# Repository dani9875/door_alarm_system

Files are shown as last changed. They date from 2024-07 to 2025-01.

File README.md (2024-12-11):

# Door alarm system
This project is a DIY smart door alarm system designed to enhance property security by providing real-time monitoring and notifications. The system detects whether a door has been opened or closed and instantly reacts to these events.

When a change is detected, the system transmits the event data through the local network to cloud services. The cloud then relays the information to a mobile application, alerting the property owner via a notification. This ensures the owner is promptly informed whenever someone enters or leaves the property.

*In case you are interested in making your own instance, please find the HW manufacturing files under the release tab.*

# How to build, flash and monitor the output the firmware
0. Check out the repository

1. Navigate to the `door_alarm_fw` directory:  
   ```bash
   cd door_alarm_fw
   ```

2. (Once) Build the Docker image by executing the following script if you have not done yet:  
   ```bash
   ./docker_build.sh
   ```

3. After the Docker image is successfully built, start the container using:  
   ```bash
   ./docker_start.sh
   ```

4. Configure the followings in *main.c* manually before build:

   ```c
   #define EXAMPLE_ESP_WIFI_SSID      "AP"
   #define EXAMPLE_ESP_WIFI_PASS      "password"

   #define EXAMPLE_STATIC_IP_ADDR        "192.168.0.100"
   #define EXAMPLE_STATIC_GW_ADDR        "192.168.0.1"
   #define EXAMPLE_STATIC_NETMASK_ADDR   "255.255.255.0"

   #define HOST "us-east-1-1.aws.cloud2.influxdata.com"
   #define PATH "/api/v2/write?orgID=[org_id]&bucket=[bucket_name]&precision=ns"
   #define TOKEN "Token [INFLUX_DB TOKEN]"
   ```

5. Inside the container, build the firmware by running:  
   ```bash
   ./build_firmware.sh
   ```

6. To program the firmware onto the device, use:  
   ```bash
   ./burn_firmware.sh
   ```

7. If you wish to observe the firmware's output, execute the monitoring script:  
   ```bash
   ./monitor_firmware.sh
   ```

## Release notes

### Version: v3.0
Changelog:
- Voltage divider resistor change
- Component library update

### Version: v2.0
Changelog:
- Component library organised
- Fuse introduced
- IP4283CZ10-TBR,115 ESD diodes

### Version: v1.0
Changelog:
- USB capability (does not work)
- USB active LED (erroneously glows even when operating from battery)
- Debug programming header
- Reed switch gate 
- Debug LED
- Voltage sense

# Technical solutions
The heart of the device is the reed sensor, which operates in normally open mode (the circuit remains open when the magnet and the reed sensor are aligned). This design choice minimizes power consumption, as no current is drawn when the door is closed. The system remains in deep sleep mode most of the time and can only be interrupted by an interaction, such as opening or closing the door. When the system wakes up, it checks the battery charge level and the door status, then initializes the WiFi connection to transmit this data to the cloud. 

A time-series data platform, [Influx](https://cloud2.influxdata.com/signup), is used to collect the data, and the data is forwarded to [Grafana](https://grafana.com/) for visualization. You can find the `grafana_door_alarm_system.json` file in the docs, which you can import to create a dashboard for monitoring the door status and battery level. Make sure to set the source ID (UID) to ensure proper functionality. 

If you would like to receive notifications about state changes, I recommend visiting [IFTTT](https://ifttt.com/explore). You can trigger events and subscribe to them. The ideal solution is to create a webhook that can be triggered from the ESP32 when it wakes up. However, this is a PRO feature. If you want to stay within the free tier, you can create a Google Sheet, set it as a trigger, and add a row (GDrive API is enabled). When a row is added, the subscriber can receive a WhatsApp message (note that with the free plan, the message may be delayed up to 1 hour).

### V2
After the component placement, I realized that the voltage measurement enable pin pad came off, so I rewired it to the LED enable pin. As a result, every time I measure the battery level, the LED briefly lights up. I also didn't have a fuse in my inventory, so I bypassed it with a direct connection. Since USB communication was functioning properly, I decided not to add the H1 straight header pins.

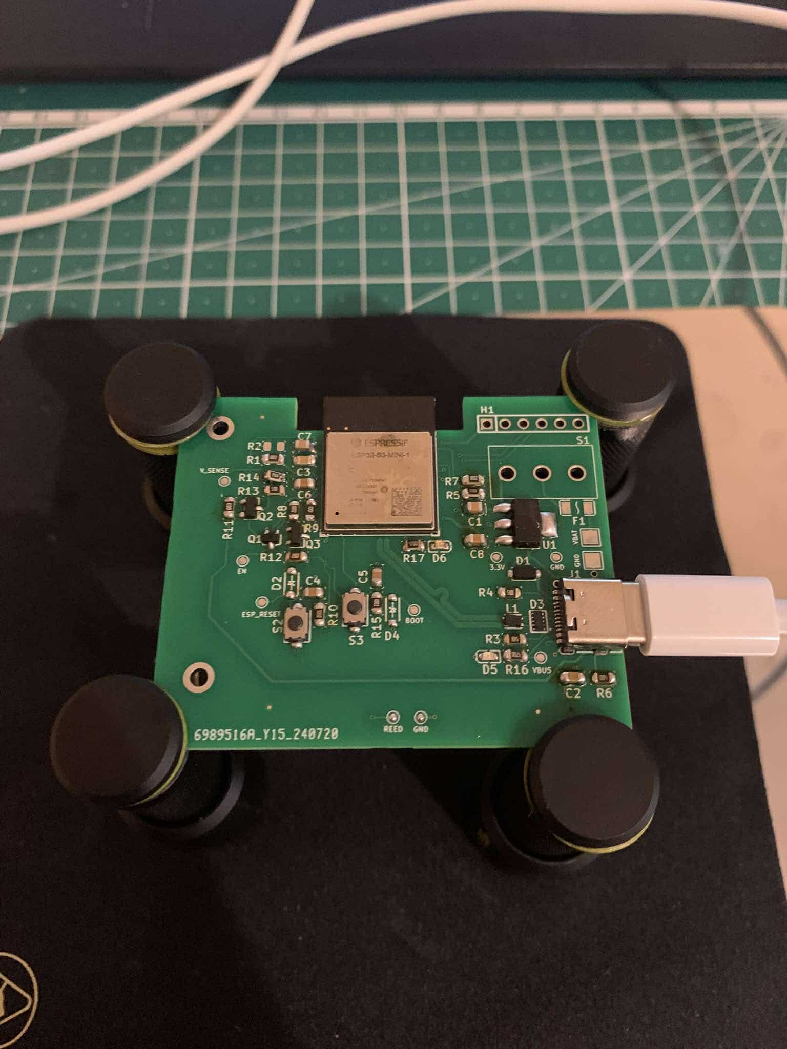
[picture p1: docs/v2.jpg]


**How to check if the USB interface is working properly:**

Run ```lsusb``` and look for a device called ```Espressif USB JTAG/serial debug unit``` 

```bash
root@c7cc3ff0b21c:/project# lsusb
Bus 004 Device 001: ID 1d6b:0003  
Bus 003 Device 003: ID 046d:c52b Logitech USB Receiver
Bus 003 Device 002: ID 13d3:54b1 Azurewave Integrated Camera
Bus 003 Device 021: ID 303a:1001 Espressif USB JTAG/serial debug unit
Bus 003 Device 004: ID 0bda:c123 Realtek Bluetooth Radio
Bus 003 Device 001: ID 1d6b:0002  
Bus 002 Device 001: ID 1d6b:0003  
Bus 001 Device 001: ID 1d6b:0002 
```

**A short code snippet (main.c, app_main()) that allows you to check if the general LED blinks:**
```c
const uint8_t led_en = GPIO_NUM_14;

void app_main(void)
{
    gpio_reset_pin(led_en);
    gpio_set_direction(led_en, GPIO_MODE_OUTPUT);

    while(1)
    {
        gpio_set_level(led_en, 1);
        vTaskDelay(pdMS_TO_TICKS(1000));
        gpio_set_level(led_en, 0);
        vTaskDelay(pdMS_TO_TICKS(1000));
    }   

    return;
}
```
In a short test, I approached the reed sensor with the magnet, which triggered a wake-up event (the LED lights up). While I held the magnet in place, nothing further happened, and the device went back to sleep. As soon as I removed the magnet, the LED flashed again, indicating that the system had woken up, similar to how it would behave if the door were opened. </br>


Although I did not have a proper casing the setup was mounted above the entrance to collect data and analyze power consumption. Data was being monitored in Grafana. 


</br>

### V1
The first version was revised because the USB interface did not work at all, and it wasn’t even impedance-controlled. As a result, it had to be programmed via the UART interface using a USB-to-TTL adapter.
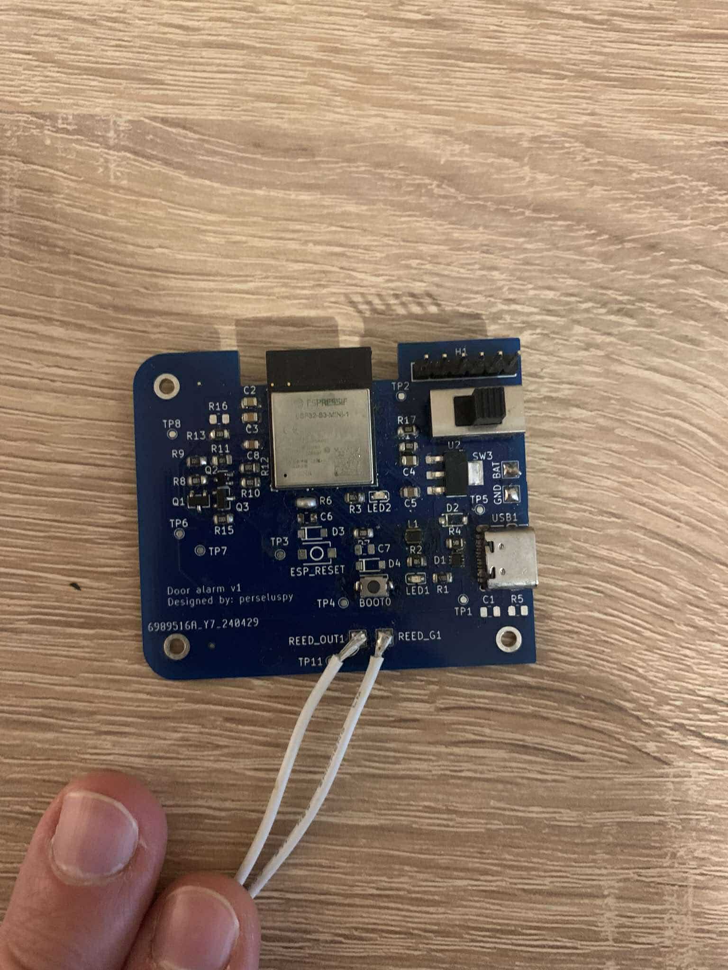
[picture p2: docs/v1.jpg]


## Consumption calculations
Power usage estimates assume the application wakes up 6 times a day (3 times for door opening and 3 times for door closing), and the system is powered by 4 AA batteries with average capacity.

| **Component** | **Current (µA)** | **Time (s)** | **Energy Contribution (µA·s)** | **Comment** |
|---|---|---|---|---|
| AP2114HA-3.3TRG1 | 60 | 86400 | 60*86400 = 5184000  | LDO operates at all times. |
| ESP32 awake doing its job  | 300000 | 60 | 300000*60 = 18000000| Wake-up duration is approximately 10 seconds. |
| Battery measurement | 240 | 60 | 240*60 = 14400 | V_SENSE divider: ~ (6 V / 25000 Ω) = 240 µA, active only during wake-up periods. |
| Reed switch closed (door open) | 330 | 45 | 330*45 = 14850 | The door is left open for a maximum of 15 seconds, and this state occurs during half of all activities. |
| ESP32 deep sleep mode | 8 | 86340 | 8*86340 = 690720 | ESP32 consumes minimal power during deep sleep. |

#### Total Energy Contribution (µA·s):
$$
5184000 + 18000000 + 14400 + 14850 + 690720 = 23903970 \ \text{µAs}
$$

#### Average Current per day (µA):
$$
\text{Average Current} = \frac{23903970}{86400} \approx 276 \ \text{µA}
$$

**Assumptions:**
**4 AA batteries** in series: Each AA battery provides **1.5V**, and the combined voltage will be **6V**. **Capacity of AA batteries**: We'll assume **2000 mAh** for typical alkaline AA batteries. **Average current consumption**: **276 µA** (0.276 mA).
</br>

#### Battery life in hours can be calculated by dividing the total battery capacity by the current draw:

$$
\text{Battery Life (hours)} = \frac{\text{Battery Capacity (mAh)}}{\text{Current Consumption (mA)}}
$$

#### For **2000 mAh** batteries and **0.276 mA** current:

$$
\text{Battery Life (hours)} = \frac{2000}{0.276} \approx 7246 \, \text{hours}
$$

#### Convert this to days:

$$
\text{Battery Life (days)} = \frac{7246}{24} \approx 302 \, \text{days}
$$

**Calculation here is not final since batteries are not drained to 0 V. Will be added after some testing. LDO shall be fed at least from 4V.** 

## Limitations/what could be improved
- HW routing is not ideal
- Local wifi credentials and static IP as well as INFLUX_DB credentials must be compiled into the project and must be set from source code
- Consumptions increase when the door is open (around 400-500 uA)
- HW and FW project is tightly-coupled making versioning obscure
- Voltage divider resistors are mixed up
- Creation of a elegant enclosure is lacked
- Some FW clean-up

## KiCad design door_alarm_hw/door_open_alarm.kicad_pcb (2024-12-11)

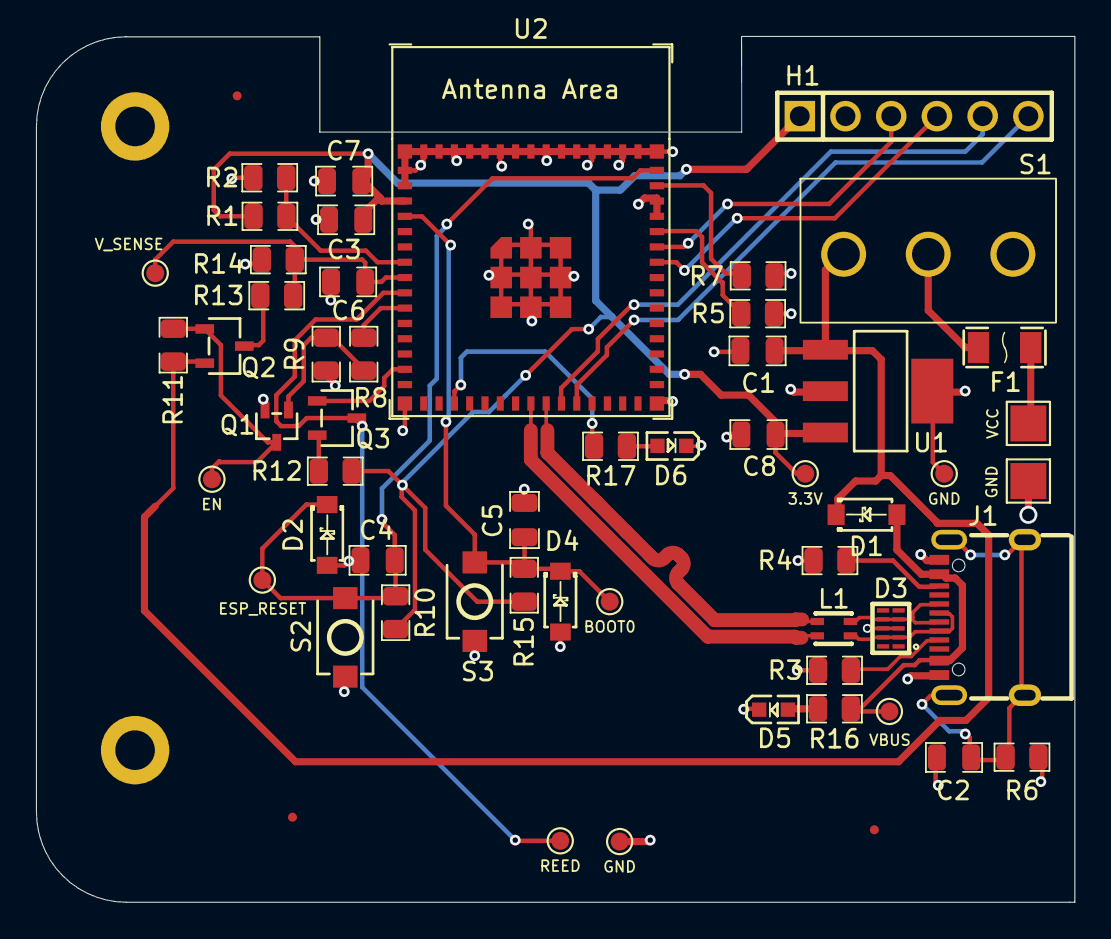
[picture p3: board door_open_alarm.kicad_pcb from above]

Board: 2 copper layers, 57.7 x 48.1 mm, 59 parts (0 on the bottom side), 33 nets.

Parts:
C1, C3, C7: CL21A106KOQNNNE; [CAP_SMD_0805_2012Metric]
C2, C8: CC0805KRX7R9BB104; [CAP_SMD_0805_2012Metric]
C4, C5, C6: C0805C105M4VACTU; [CAP_SMD_0805_2012Metric]
D1, D2, D4: STPS140Z; [SCHOTTKY_DIODE_40V]STMicroelectronics STPS140Z
D3: IP4283CZ10-TBR,115; [ESD_PROT]Nexperia IP4283CZ10-TBR,115
D5, D6: LTST-C190KRKT; [LED]Lite-On LTST-C190KRKT
F1: 0466.200NRHF; [FUSE_SMD_1206]
FID1, FID2, FID3: Fiducial; Fiducial_0.5mm_Mask1mm
H1: PZ254V-11-06P; [6P_HEADER_STR]XFCN PZ254V-11-06P
J1: TYPE-C 16PIN 2MD(073); [USB_C_16P_RA_FEMALE]SHOU HAN TYPE-C 16PIN 2MD(073)
L1: DLW21SN900SQ2L; [COMMON_MODE_FILTER]Murata Electronics DLW21SN900SQ2L
MH1, MH2: [MOUNTING_HOLE]MountingHole_2.2mm_M2_DIN965_Pad
Q1: BSS138PW,115; [NMOS]Nexperia BSS138PW,115
Q2, Q3: CJ2301 S1; [PMOS]Jiangsu Changjing Electronics Technology Co., Ltd. CJ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
R1, R2, R5, R7, R9, R10, R12, R15: 0805W8F1002T5E; [RES_SMD_0805_2012Metric]
R3, R4, R14: 0805W8F5101T5E; [RES_SMD_0805_2012Metric]
R6: 0805W8F1004T5E; [RES_SMD_0805_2012Metric]
R8: 0805W8F1001T5E; [RES_SMD_0805_2012Metric]
R11: 0805W8F1003T5E; [RES_SMD_0805_2012Metric]
R13: 0805W8J0203T5E; [RES_SMD_0805_2012Metric]
R16, R17: 0805W8F4700T5E; [RES_SMD_0805_2012Metric]
S1: SS-12D10L5; [SLIDE_SWITCH]XKB Connection SS-12D10L5
S2, S3: TS-1088-AR02016; [TACTILE_SWITCH]XUNPU TS-1088-AR02016
TP1: VBUS; [TEST_POINT]TestPoint_Pad_D1.0mm
TP2: VCC; [TEST_POINT]TestPoint_Pad_2.0x2.0mm
TP3: GND; [TEST_POINT]TestPoint_Pad_2.0x2.0mm
TP4, TP6: GND; [TEST_POINT]TestPoint_Pad_D1.0mm
TP5: 3.3V; [TEST_POINT]TestPoint_Pad_D1.0mm
TP7: ESP_RESET; [TEST_POINT]TestPoint_Pad_D1.0mm
TP8: EN; [TEST_POINT]TestPoint_Pad_D1.0mm
TP9: REED; [TEST_POINT]TestPoint_Pad_D1.0mm
TP10: V_SENSE; [TEST_POINT]TestPoint_Pad_D1.0mm
TP11: BOOT0; [TEST_POINT]TestPoint_Pad_D1.0mm
U1: AP2114HA-3.3TRG1; [LDO]Diodes Incorporated AP2114HA-3.3TRG1
U2: ESP32-S3-MINI-1; [MCU]Espressif Systems ESP32-S3-MINI-1-N8

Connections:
+3.3V: C3.1, C7.1, C8.2, H1.1, R1.2, R10.2, R12.2, R15.2, TP5.1, U1.3 (OUT), U2.3 (3V3)
/BOOT0: C5.2, D4.1 (C), R15.1, S3.2, TP11.1, U2.4 (GPIO0/BOOT)
/D+: D3.4 (TMDS_CH2-), D3.7 (NC), J1.6 (DP1), J1.8 (DP2), L1.4
/D-: D3.2 (TMDS_CH1+), D3.9 (NC), J1.5 (DN2), J1.7 (DN1), L1.1
/EN: Q1.3 (D), Q2.1 (G), R11.1, TP8.1
/ESP_RESET: C4.2, D2.1 (C), R10.1, S2.2, TP7.1, U2.45 (EN)
/GEN_1: H1.5, U2.25 (GPIO21)
/GEN_2: H1.6, U2.26 (GPIO26)
/LED_EN: R17.2, U2.18 (GPIO14/TOUCH14/ADC2_CH3/FSPIWP/FSPIDQS/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)
/MEAS_EN: R8.1, U2.10 (GPIO6/TOUCH6/ADC1_CH5)
/REED: Q3.3 (D), TP9.1, U2.9 (GPIO5/TOUCH5/ADC1_CH4)
/REED_EN: Q3.1 (G), U2.14 (GPIO10/TOUCH10/ADC1_CH9/FSPICS0/FSPIIO4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)
/SHIELD: C2.1, J1.13 (SHELL), J1.14 (SHELL), R6.1
/STRAP_3: R1.1, R2.2, U2.7 (GPIO3/TOUCH3/ADC1_CH2)
/STRAP_45: R5.2, U2.41 (GPIO45)
/STRAP_46: R7.2, U2.44 (GPIO46)
/U0_RX: H1.3, U2.40 (U0RXD/GPIO44/CLK_OUT2)
/U0_TX: H1.4, U2.39 (U0TXD/GPIO43/CLK_OUT1)
/USB_D+: L1.3, U2.24 (GPIO20/U1CTS/ADC2_CH9/CLK_OUT1/USB_D+)
/USB_D-: L1.2, U2.23 (GPIO19/U1RTS/ADC2_CH8/CLK_OUT2/USB_D-)
/VBUS: D1.2 (A), J1.2 (VBUS), J1.11 (VBUS), R16.2, TP1.1
/V_INPUT: C1.1, D1.1 (C), Q2.2 (S), R11.2, S1.1, U1.1 (IN)
/V_SENSE: C6.2, R13.1, R14.2, TP10.1, U2.8 (GPIO4/TOUCH4/ADC1_CH3)
GND: C1.2, C2.2, C3.2, C4.1, C5.1, C6.1, C7.2, C8.1, D2.2 (A), D3.3 (GND), D3.8 (GND), D4.2 (A), D5.2 (C), D6.2 (C), H1.2, J1.1 (GND), J1.12 (GND), MH1.1, MH2.1, Q1.2 (S), R2.1, R3.1, R4.1, R5.1, R6.2, R7.1, R9.1, R14.1, S2.1, S3.1, TP3.1, TP4.1, TP6.1, U1.2 (GND), U1.4 (GND), U2.1 (GND), U2.2 (GND), U2.42 (GND), U2.43 (GND), U2.46 (GND), U2.47 (GND), U2.48 (GND), U2.49 (GND), U2.50 (GND), U2.51 (GND), U2.52 (GND), U2.53 (GND), U2.54 (GND), U2.55 (GND), U2.56 (GND), U2.57 (GND), U2.58 (GND), U2.59 (GND), U2.60 (GND), U2.61 (GND), U2.62 (GND), U2.63 (GND), U2.64 (GND), U2.65 (GND)
unnamed: D5.1 (A), R16.1
unnamed: D6.1 (A), R17.1
unnamed: F1.2, S1.2
unnamed: J1.4 (CC1), R3.2
unnamed: J1.10 (CC2), R4.2
unnamed: Q1.1 (G), R8.2, R9.2
unnamed: Q2.3 (D), R13.2
unnamed: Q3.2 (S), R12.1
VCC: F1.1, TP2.1

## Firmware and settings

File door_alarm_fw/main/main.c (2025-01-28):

#include "cJSON.h"
#include "driver/gpio.h"
#include "driver/touch_pad.h"
#include "driver/usb_serial_jtag.h"
#include "freertos/FreeRTOS.h"
#include "freertos/event_groups.h"
#include "freertos/semphr.h"
#include "freertos/task.h"
#include <stdint.h>
#include <stdio.h>
#include "esp_log.h"
#include "minunit.h"
#include <stdlib.h>
#include "esp_adc/adc_cali.h"
#include "esp_adc/adc_cali_scheme.h"
#include "esp_adc/adc_oneshot.h"
#include <string.h>
#include "esp_sleep.h"
#include "esp_system.h"
#include "esp_wifi.h"
#include "driver/rtc_io.h"
#include "esp_event.h"
#include "nvs_flash.h"
#include "esp_http_client.h"
#include "esp_tls.h"
#if CONFIG_MBEDTLS_CERTIFICATE_BUNDLE
#include "esp_crt_bundle.h"
#endif
#include "mbedtls/ctr_drbg.h"
#include <mbedtls/entropy.h>

#include "lwip/err.h"
#include "lwip/sys.h"

/* The examples use WiFi configuration that you can set via project configuration menu

   If you'd rather not, just change the below entries to strings with
   the config you want - ie #define EXAMPLE_WIFI_SSID "mywifissid"
*/
#define EXAMPLE_ESP_WIFI_SSID      "[AP_NAME]"
#define EXAMPLE_ESP_WIFI_PASS      "[PASSWORD]"
#define EXAMPLE_ESP_MAXIMUM_RETRY  3
#define CONFIG_ESP_WIFI_AUTH_WPA2_PSK 1

#define EXAMPLE_STATIC_IP_ADDR        "[STATIC_IP]"
#define EXAMPLE_STATIC_GW_ADDR        "[GATEWAY]"
#define EXAMPLE_STATIC_NETMASK_ADDR   "[NETMASK]"

#define HOST "us-east-1-1.aws.cloud2.influxdata.com"
#define PATH "/api/v2/write?orgID=[ID]a08ec8&bucket=[BUCKET_NAME]&precision=ns"
#define TOKEN "Token [your token]"


#if CONFIG_ESP_WPA3_SAE_PWE_HUNT_AND_PECK
#define ESP_WIFI_SAE_MODE WPA3_SAE_PWE_HUNT_AND_PECK
#define EXAMPLE_H2E_IDENTIFIER ""
#elif CONFIG_ESP_WPA3_SAE_PWE_HASH_TO_ELEMENT
#define ESP_WIFI_SAE_MODE WPA3_SAE_PWE_HASH_TO_ELEMENT
#define EXAMPLE_H2E_IDENTIFIER CONFIG_ESP_WIFI_PW_ID
#elif CONFIG_ESP_WPA3_SAE_PWE_BOTH
#define ESP_WIFI_SAE_MODE WPA3_SAE_PWE_BOTH
#define EXAMPLE_H2E_IDENTIFIER CONFIG_ESP_WIFI_PW_ID
#endif
#if CONFIG_ESP_WIFI_AUTH_OPEN
#define ESP_WIFI_SCAN_AUTH_MODE_THRESHOLD WIFI_AUTH_OPEN
#elif CONFIG_ESP_WIFI_AUTH_WEP
#define ESP_WIFI_SCAN_AUTH_MODE_THRESHOLD WIFI_AUTH_WEP
#elif CONFIG_ESP_WIFI_AUTH_WPA_PSK
#define ESP_WIFI_SCAN_AUTH_MODE_THRESHOLD WIFI_AUTH_WPA_PSK
#elif CONFIG_ESP_WIFI_AUTH_WPA2_PSK
#define ESP_WIFI_SCAN_AUTH_MODE_THRESHOLD WIFI_AUTH_WPA2_PSK
#elif CONFIG_ESP_WIFI_AUTH_WPA_WPA2_PSK
#define ESP_WIFI_SCAN_AUTH_MODE_THRESHOLD WIFI_AUTH_WPA_WPA2_PSK
#elif CONFIG_ESP_WIFI_AUTH_WPA3_PSK
#define ESP_WIFI_SCAN_AUTH_MODE_THRESHOLD WIFI_AUTH_WPA3_PSK
#elif CONFIG_ESP_WIFI_AUTH_WPA2_WPA3_PSK
#define ESP_WIFI_SCAN_AUTH_MODE_THRESHOLD WIFI_AUTH_WPA2_WPA3_PSK
#elif CONFIG_ESP_WIFI_AUTH_WAPI_PSK
#define ESP_WIFI_SCAN_AUTH_MODE_THRESHOLD WIFI_AUTH_WAPI_PSK
#endif


// #define TESTING_WITH_MINUNIT    //include this if you want to run tests with minunit, otherwise that code is not included
#ifdef TESTING_WITH_MINUNIT
int mu_test_runner(void);
#endif

/* FreeRTOS event group to signal when we are connected*/
static EventGroupHandle_t s_wifi_event_group;

/* The event group allows multiple bits for each event, but we only care about two events:
 * - we are connected to the AP with an IP
 * - we failed to connect after the maximum amount of retries */
#define WIFI_CONNECTED_BIT BIT0
#define WIFI_FAIL_BIT      BIT1

static int s_retry_num = 0;

// RTC_DATA_ATTR uint8_t prev_level = 0;
uint8_t prev_level = 0;

adc_cali_handle_t                       cali_handle;
adc_oneshot_unit_handle_t               adc_handle;
const uint8_t reed_en = GPIO_NUM_10;
const uint8_t door_sensor = GPIO_NUM_5;
const uint8_t meas_en = GPIO_NUM_6;
const uint8_t led_en = GPIO_NUM_14;


float voltage;
uint8_t level = 0;


static char       TAG[] = "MAIN";

void adc_init(adc_unit_t adcunit, adc_channel_t chan, adc_atten_t atten, adc_bitwidth_t bitwidth)
{
    adc_oneshot_unit_init_cfg_t init_config = {.unit_id = adcunit};

    esp_err_t ret                           = adc_oneshot_new_unit(&init_config, &adc_handle);
    if(ret != ESP_OK)
    {
        ESP_LOGE(TAG, "ADC unit initialization failed.");

        return;
    }

    adc_oneshot_chan_cfg_t config = {
        .bitwidth = bitwidth,
        .atten    = atten,
    };

    ret = adc_oneshot_config_channel((adc_handle), (chan), &config);

    if(ret != ESP_OK)
    {
        ESP_LOGE(TAG, "ADC channel configuration failed.");

        return;
    }

    adc_cali_curve_fitting_config_t cali_config = {
        .unit_id  = adcunit,
        .atten    = atten,
        .bitwidth = bitwidth,
    };

    ret = adc_cali_create_scheme_curve_fitting(&cali_config, &(cali_handle));

    if(ret != ESP_OK)
    {
        ESP_LOGE(TAG, "ADC curve fitting failed.");

        return;
    }

    return;
}

// void post_event()
// {
//     esp_http_client_config_t config_post = {.host              = "maker.ifttt.com",
//                                             .path              = "/trigger/door_event/json/with/key/dJvviPf6PCdAXrUKria3fc",
//                                             .method            = HTTP_METHOD_POST,
//                                             .transport_type    = HTTP_TRANSPORT_OVER_SSL,
//                                             .crt_bundle_attach = esp_crt_bundle_attach};

//     esp_http_client_handle_t client      = esp_http_client_init(&config_post);

//     cJSON* root                          = cJSON_CreateObject();
//     cJSON_AddStringToObject(root, "door_state", "open");

//     char* jsonString = cJSON_Print(root);
//     printf("%s\n", jsonString);

//     // Set headers
//     esp_http_client_set_header(client, "Content-Type", "application/json");

//     // Set POST data
//     esp_http_client_set_post_field(client, jsonString, strlen(jsonString));
//     esp_http_client_perform(client);

//     esp_http_client_cleanup(client);

//     cJSON_Delete(root);
//     free(jsonString);

//     return;
// }

void post_event() {
    esp_http_client_config_t config_post = {
        .host              = HOST,
        .path              = PATH,
        .method            = HTTP_METHOD_POST,
        .transport_type    = HTTP_TRANSPORT_OVER_SSL,
        .crt_bundle_attach = esp_crt_bundle_attach
    };

    esp_http_client_handle_t client = esp_http_client_init(&config_post);

    // Create the inner JSON string
    char door_status[50] = {0};
    snprintf(door_status, sizeof(door_status), "charge=%.2f,door_state=%d", voltage, level);

    cJSON* inner = cJSON_CreateObject();
    if (inner == NULL) {
        ESP_LOGE(TAG, "Failed to create inner JSON object");
        return;
    }
    cJSON_AddStringToObject(inner, "door_status", door_status);

    char* innerJsonString = cJSON_PrintUnformatted(inner);
    if (innerJsonString == NULL) {
        ESP_LOGE(TAG, "Failed to serialize inner JSON");
        cJSON_Delete(inner);
        return;
    }
    cJSON_Delete(inner); // Cleanup after inner JSON

    // Create the outer JSON object
    cJSON* outer = cJSON_CreateObject();
    if (outer == NULL) {
        ESP_LOGE(TAG, "Failed to create outer JSON object");
        free(innerJsonString);
        return;
    }
    cJSON_AddStringToObject(outer, "body", innerJsonString);

    char* outerJsonString = cJSON_Print(outer);
    if (outerJsonString == NULL) {
        ESP_LOGE(TAG, "Failed to serialize outer JSON");
        cJSON_Delete(outer);
        free(innerJsonString);
        return;
    }

    ESP_LOGI(TAG, "Final JSON payload: %s", outerJsonString);

    // Set headers
    esp_http_client_set_header(client, "Content-Type", "application/json");
    esp_http_client_set_header(client, "x-api-key", TOKEN);

    // Set POST field
    esp_http_client_set_post_field(client, outerJsonString, strlen(outerJsonString));

    // Perform POST request
    esp_err_t err = esp_http_client_perform(client);
    if (err == ESP_OK) {
        ESP_LOGI(TAG, "HTTP POST Status = %d", esp_http_client_get_status_code(client));
    } else {
        ESP_LOGE(TAG, "HTTP POST request failed: %s", esp_err_to_name(err));
    }

    // Clean up
    esp_http_client_cleanup(client);
    cJSON_Delete(outer);
    free(innerJsonString);
    free(outerJsonString);
}

static void example_set_static_ip(esp_netif_t *netif)
{
    if (esp_netif_dhcpc_stop(netif) != ESP_OK) {
        ESP_LOGE(TAG, "Failed to stop dhcp client");
        return;
    }
    esp_netif_ip_info_t ip;
    memset(&ip, 0 , sizeof(esp_netif_ip_info_t));
    ip.ip.addr = ipaddr_addr(EXAMPLE_STATIC_IP_ADDR);
    ip.netmask.addr = ipaddr_addr(EXAMPLE_STATIC_NETMASK_ADDR);
    ip.gw.addr = ipaddr_addr(EXAMPLE_STATIC_GW_ADDR);
    if (esp_netif_set_ip_info(netif, &ip) != ESP_OK) {
        ESP_LOGE(TAG, "Failed to set ip info");
        return;
    }
    ESP_LOGD(TAG, "Success to set static ip: %s, netmask: %s, gw: %s", EXAMPLE_STATIC_IP_ADDR, EXAMPLE_STATIC_NETMASK_ADDR, EXAMPLE_STATIC_GW_ADDR);
}

static void event_handler(void* arg, esp_event_base_t event_base,
                                int32_t event_id, void* event_data)
{
    if (event_base == WIFI_EVENT && event_id == WIFI_EVENT_STA_START) 
    {
        esp_wifi_connect();
    }
    else if (event_base == WIFI_EVENT && event_id == WIFI_EVENT_STA_CONNECTED)
    {
        example_set_static_ip(arg);
    }
    else if (event_base == WIFI_EVENT && event_id == WIFI_EVENT_STA_DISCONNECTED) {
        if (s_retry_num < EXAMPLE_ESP_MAXIMUM_RETRY) {
            esp_wifi_connect();
            s_retry_num++;
            ESP_LOGI(TAG, "retry to connect to the AP");
        } else {
            xEventGroupSetBits(s_wifi_event_group, WIFI_FAIL_BIT);
        }
        ESP_LOGI(TAG,"connect to the AP fail");
    } else if (event_base == IP_EVENT && event_id == IP_EVENT_STA_GOT_IP) {
        ip_event_got_ip_t* event = (ip_event_got_ip_t*) event_data;
        ESP_LOGI(TAG, "got ip:" IPSTR, IP2STR(&event->ip_info.ip));
        s_retry_num = 0;
        xEventGroupSetBits(s_wifi_event_group, WIFI_CONNECTED_BIT);
    }
}

void wifi_init_sta(void)
{
    s_wifi_event_group = xEventGroupCreate();

    ESP_ERROR_CHECK(esp_netif_init());

    ESP_ERROR_CHECK(esp_event_loop_create_default());

    esp_netif_t *my_sta = esp_netif_create_default_wifi_sta();
    assert(my_sta);

    

    wifi_init_config_t cfg = WIFI_INIT_CONFIG_DEFAULT();
    ESP_ERROR_CHECK(esp_wifi_init(&cfg));

    esp_event_handler_instance_t instance_any_id;
    esp_event_handler_instance_t instance_got_ip;
    ESP_ERROR_CHECK(esp_event_handler_instance_register(WIFI_EVENT,
                                                        ESP_EVENT_ANY_ID,
                                                        &event_handler,
                                                        NULL,
                                                        &instance_any_id));
    ESP_ERROR_CHECK(esp_event_handler_instance_register(IP_EVENT,
                                                        IP_EVENT_STA_GOT_IP,
                                                        &event_handler,
                                                        NULL,
                                                        &instance_got_ip));

    wifi_config_t wifi_config = {
        .sta = {
            .ssid = EXAMPLE_ESP_WIFI_SSID,
            .password = EXAMPLE_ESP_WIFI_PASS,
            /* Authmode threshold resets to WPA2 as default if password matches WPA2 standards (pasword len => 8).
             * If you want to connect the device to deprecated WEP/WPA networks, Please set the threshold value
             * to WIFI_AUTH_WEP/WIFI_AUTH_WPA_PSK and set the password with length and format matching to
             * WIFI_AUTH_WEP/WIFI_AUTH_WPA_PSK standards.
             */
            .threshold.authmode = ESP_WIFI_SCAN_AUTH_MODE_THRESHOLD,
            // .sae_pwe_h2e = ESP_WIFI_SAE_MODE,
            // .sae_h2e_identifier = EXAMPLE_H2E_IDENTIFIER,
        },
    };
    ESP_ERROR_CHECK(esp_wifi_set_mode(WIFI_MODE_STA) );
    ESP_ERROR_CHECK(esp_wifi_set_config(WIFI_IF_STA, &wifi_config) );
    ESP_ERROR_CHECK(esp_wifi_start() );

    ESP_LOGI(TAG, "wifi_init_sta finished.");

    /* Waiting until either the connection is established (WIFI_CONNECTED_BIT) or connection failed for the maximum
     * number of re-tries (WIFI_FAIL_BIT). The bits are set by event_handler() (see above) */
    EventBits_t bits = xEventGroupWaitBits(s_wifi_event_group,
            WIFI_CONNECTED_BIT | WIFI_FAIL_BIT,
            pdFALSE,
            pdFALSE,
            portMAX_DELAY);

    /* xEventGroupWaitBits() returns the bits before the call returned, hence we can test which event actually
     * happened. */
    if (bits & WIFI_CONNECTED_BIT) {
        ESP_LOGI(TAG, "connected to ap SSID:%s password:%s",
                 EXAMPLE_ESP_WIFI_SSID, EXAMPLE_ESP_WIFI_PASS);
    } else if (bits & WIFI_FAIL_BIT) {
        ESP_LOGI(TAG, "Failed to connect to SSID:%s, password:%s",
                 EXAMPLE_ESP_WIFI_SSID, EXAMPLE_ESP_WIFI_PASS);
    } else {
        ESP_LOGE(TAG, "UNEXPECTED EVENT");
    }

    post_event();
}

static char* mu_TestBoilingPt()
{
    uint8_t c, f;
    c = 100;
    f = 212;
    mu_assert("mu_TestBoilingPt Failed, f != 212", c==f);
    return 0;
}

//TODO more tests go here

//top level test functions
static char* mu_all_tests()
{
    ESP_LOGI(TAG,"Running MINUNIT mu_TestBoilingPt...\n");
    mu_run_test(mu_TestBoilingPt);
    
    //TODO call more tests from here
    
    return 0;
}

int mu_test_runner()
{
    ESP_LOGI(TAG, "Starting MINUNIT Tests\n");

    char* result = mu_all_tests();
    if (result)
    {
        ESP_LOGI(TAG, "%s\n", result);
    }
    else
    {
        ESP_LOGI(TAG, "ALL MINUNIT TESTS PASSED\n");
    }
    ESP_LOGI(TAG, "MINUNIT Tests run: %d\n", mu_tests_run);

    return result != 0;
}

void app_main(void)
{
  
#ifdef TESTING_WITH_MINUNIT    //run the tests
    int mu_result = mu_test_runner();

    if (mu_result)
    {
        ESP_LOGE(TAG, "Failed test(s)...");
        
        return;
    }
#endif
    uint16_t adc_raw;
    uint16_t vbus_V;

    esp_err_t ret = nvs_flash_init();
    if (ret == ESP_ERR_NVS_NO_FREE_PAGES || ret == ESP_ERR_NVS_NEW_VERSION_FOUND) 
    {
      ESP_ERROR_CHECK(nvs_flash_erase());
      ret = nvs_flash_init();
    }

    ESP_ERROR_CHECK(ret);

     switch (esp_sleep_get_wakeup_cause()) 
     {
        case ESP_SLEEP_WAKEUP_EXT0:
        {
            ESP_LOGI(TAG, "Wake up from ext0");
            break;
        }
        case ESP_SLEEP_WAKEUP_EXT1: {
            uint64_t wakeup_pin_mask = esp_sleep_get_ext1_wakeup_status();
            if (wakeup_pin_mask != 0) {
                int pin = __builtin_ffsll(wakeup_pin_mask) - 1;
                ESP_LOGI(TAG, "Wake up from GPIO %d\n", pin);
            } else {
                ESP_LOGI(TAG, "Wake up from GPIO\n");
            }
            break;
        }
        case ESP_SLEEP_WAKEUP_TIMER: 
        {
            ESP_LOGI(TAG, "Wake up from timer. Time spent in deep sleep\n");
            break;
        }
        default:
        break;
     }


    gpio_reset_pin(led_en);
    gpio_set_direction(led_en, GPIO_MODE_OUTPUT);
    gpio_set_level(led_en, 1);
    vTaskDelay(pdMS_TO_TICKS(200));

    adc_init(ADC_UNIT_1, ADC_CHANNEL_3, ADC_ATTEN_DB_11, ADC_BITWIDTH_DEFAULT);
    vTaskDelay(pdMS_TO_TICKS(1000));

    adc_oneshot_read(adc_handle, ADC_CHANNEL_3, &adc_raw);
    adc_cali_raw_to_voltage(cali_handle, adc_raw, &vbus_V);

    gpio_set_level(led_en, 0);

    voltage = (25.1/5.1)*((float)vbus_V/1000);

    ESP_LOGI("MAIN", "Voltage level: %f", voltage);
    ESP_LOGI("MAIN", "Voltage level raw: %d", vbus_V);

    rtc_gpio_hold_dis(reed_en);
    rtc_gpio_init(reed_en);
    rtc_gpio_set_direction(reed_en, RTC_GPIO_MODE_OUTPUT_ONLY);
    rtc_gpio_set_level(reed_en, 0);

    vTaskDelay(pdMS_TO_TICKS(10));

    gpio_reset_pin(door_sensor);
    gpio_set_direction(door_sensor, GPIO_MODE_INPUT);
    level = 0;
    level = gpio_get_level(door_sensor);
    ESP_LOGI("MAIN", "Door sensor state: %d", level);
    esp_sleep_disable_wakeup_source(ESP_SLEEP_WAKEUP_ALL);

    if(level == 0)
    {

        esp_sleep_enable_ext0_wakeup(door_sensor, 1);

        rtc_gpio_pullup_en(door_sensor);
        rtc_gpio_set_level(reed_en, 0);
        rtc_gpio_hold_en(reed_en); 
        ESP_LOGI("MAIN", "Open door");

    }
    else
    {
        esp_sleep_enable_ext0_wakeup(door_sensor, 0);

        rtc_gpio_pullup_en(door_sensor);
        rtc_gpio_set_level(reed_en, 0);
        rtc_gpio_hold_en(reed_en); 
        ESP_LOGI("MAIN", "Closed door");
    }
    prev_level = level;

    wifi_init_sta();
    esp_wifi_stop();
    esp_deep_sleep_start();

    return;
}

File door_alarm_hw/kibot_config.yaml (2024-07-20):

kibot:
  version: 1

preflight:
  erc:
    enabled: true
    dir: fabrication_output/rule_checks
    format: ["HTML", "RPT"]
    output: "%f-%i%I%v.%x"
    dont_stop: false
  check_zone_fills: true

outputs:
  - name: 'gerbers'
    type: gerber
    dir: fabrication_output/manufacturing/gerbers_and_drills
    options:
      # generic layer options
      exclude_edge_layer: true
      exclude_pads_from_silkscreen: false
      plot_sheet_reference: false
      plot_footprint_refs: true
      plot_footprint_values: true
      force_plot_invisible_refs_vals: false
      tent_vias: true
      
      # gerber options
      line_width: 0.1
      subtract_mask_from_silk: false
      use_protel_extensions: false
      gerber_precision: 4.5
      create_gerber_job_file: true
      use_gerber_x2_attributes: true
      use_gerber_net_attributes: true

    layers:
      - F.Cu
      - B.Cu
      - F.SilkS
      - B.SilkS
      - F.Mask
      - B.Mask
      - User.Drawings
      - User.Comments
      - Edge.Cuts
      - F.Courtyard
      - B.Courtyard
      - F.Fab
      - B.Fab

  - name: 'drill_files'
    type: excellon
    dir: fabrication_output/manufacturing/gerbers_and_drills
    options:
      metric_units: true
      pth_and_npth_single_file: false

  - name: compress_fab
    comment: "Generates a ZIP file with all the fab outputs"
    type: compress
    run_by_default: true
    dir: fabrication_output/manufacturing/
    options:
      files:
        - from_output: gerbers
          dest: gerbers/
        - from_output: drill_files
          dest: drill_files/
      format: ZIP
      output: "plug_of_nails_gerbers_and_drills.%x"

  - name: 'bom'
    comment: "BoM general format"
    type: bom
    dir: fabrication_output/manufacturing/general_bom_and_pick_and_place
    options:
      output: 'plug_of_nails_bom_general.%x'
      ref_separator: ','
      columns:
        - field: 'Quantity Per Pcb'
          name: 'Quantity'
        - field: Value
          name: Value
        - field: References
          name: Parts
        - field: Manufacturer
          name: Manufacturer
        - field: 'Description'
          name: 'Description'
      csv:
        hide_pcb_info: true
        hide_stats_info: true
        quote_all: true

  - name: 'bom_jlc'
    comment: "BoM for JLC"
    type: bom
    dir: fabrication_output/manufacturing/jlc_bom_and_pick_and_place
    options:
      output: 'plug_of_nails_bom_jlc.%x'
      ref_separator: ','
      columns:
        - field: Value
          name: Comment
        - field: References
          name: Designator
        - Footprint
        - field: 'LCSC Part'
          name: 'LCSC Part #'
      csv:
        hide_pcb_info: true
        hide_stats_info: true
        quote_all: true

  - name: 'position'
    comment: "Pick and place file, general style"
    type: position
    dir: fabrication_output/manufacturing/general_bom_and_pick_and_place
    options:
      output: 'plug_of_nails_pick_and_place_general.%x'
      format: CSV
      only_smd: false
      units: millimeters
      separate_files_for_front_and_back: false

  - name: 'position_jlc'
    comment: "Pick and place file, JLC style"
    type: position
    dir: fabrication_output/manufacturing/jlc_bom_and_pick_and_place
    options:
      output: 'plug_of_nails_pick_and_place_jlc.%x'
      format: CSV
      units: millimeters
      separate_files_for_front_and_back: false
      only_smd: false
      columns:
        - id: Ref
          name: Designator
        - Val
        - Package
        - id: PosX
          name: "Mid X"
        - id: PosY
          name: "Mid Y"
        - id: Rot
          name: Rotation
        - id: Side
          name: Layer

  - name: 'print_sch'
    comment: "Print schematic (PDF)"
    type: pdf_sch_print
    dir: fabrication_output
    options:
      output: schematic.pdf

  - name: "base"
    dir: fabrication_output/capture
    type: render_3d
    run_by_default: false
    options:
      ray_tracing: false
      width: 2000
      height: 1000

  - name: "top"
    comment: "Top view"
    dir: fabrication_output/capture
    type: render_3d
    extends: "base"
    options:
      rotate_x: 3
      rotate_z: -2
      output: "pcb_3d_render_top.png"

  - name: "bottom"
    comment: "Bottom view"
    dir: fabrication_output/capture
    type: render_3d
    extends: "top"
    options:
      width: 1920
      view: "bottom"
      output: "pcb_3d_render_bottom.png"

  - name: 'board_image_top'
    comment: "Image of PCB"
    type: pcbdraw
    dir: fabrication_output/capture
    options:
      bottom: false
      format: "png"
      output: "pcb_2d_image_top.png"

  - name: 'board_image_bottom'
    comment: "Image of PCB"
    type: pcbdraw
    dir: fabrication_output/capture
    options:
      bottom: true
      format: "png"
      output: "pcb_2d_image_bottom.png"
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

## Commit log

2024-05-14 Removing manuf files
    [door_open_alarm-B_Cu.gbr, door_open_alarm-B_Mask.gbr, door_open_alarm-B_Paste.gbr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]
2024-05-14 Init fw files
    [partition_table.csv]
2024-06-04 Gathering HW files in one folder
    [door_open_alarm.kicad_pcb, door_open_alarm.kicad_sch]
2024-06-05 Posting event to IFTTT
    [door_open_alarm.csv]
2024-06-27 Bulk change after component lib change
    [door_open_alarm.kicad_pcb, door_open_alarm.kicad_sch]
2024-06-28 Updating components and design as well as yaml
    [door_open_alarm.kicad_pcb, door_open_alarm.kicad_sch]
2024-12-06 Changes due to library update (minor)
    [door_open_alarm.kicad_pcb, door_open_alarm.kicad_sch]
2024-12-11 Resistor mix up fix, label fix
    [door_open_alarm.kicad_pcb, door_open_alarm.kicad_sch]
2024-12-11 Mounted setup docs appended
